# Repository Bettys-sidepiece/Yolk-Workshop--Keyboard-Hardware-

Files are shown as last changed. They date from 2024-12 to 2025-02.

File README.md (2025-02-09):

## License

The Yolk Keyboard hardware is licensed under the **TAPR Open Hardware License (TAPR OHL).**  
License: TAPR OHL  
[Read the full license](https://www.tapr.org/ohl.html)  

### **About the Yolk Keyboard Hardware**
The Yolk Keyboard consists of four PCBs:
- **Slaptic System**: Slide + haptic feedback module
- **Germinal Disc**: Keyboard (human input device)
- **Vitillus**: Main controller PCB
- **Proximity Sensor**: Detects user presence

### **Core Components**
- **Microcontroller**: STM32L702
- **Bluetooth Module**: Microchip BM71 for BLE connectivity
- **Lighting**: RGB LEDs
- **Additional Features**: Haptic feedback, capacitive touch sensing, and advanced power management

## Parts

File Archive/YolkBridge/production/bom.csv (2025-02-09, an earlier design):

Designator | Footprint | Quantity | Value | LCSC Part #
C1, C2, C3, C5 | 0603 | 4 | 100n
C4 | 0603 | 1 | 470n
C6, C7 | 0603 | 2 | 1u
D1 | D_SOD-323_HandSoldering | 1 | BAT60BE6359HTMA1
D2 | 0603 | 1 | TXLED
D3 | 0603 | 1 | RXLED
D4 | SOT-23-6 | 1 | ESDA6V1BC6
FB1 | 0603 | 1 | 100R @ 100MHz
J1 | USB_A_Molex_48037-2200_Horizontal | 1 | USB_A
J2 | 5037630491 | 1 | UART
R1, R2 | 0603 | 2 | 27R
R3, R4 | 0603 | 2 | 10k
R5, R6 | 0603 | 2 | 330R
U1 | SOT-23-6 | 1 | USBLC6-2SC6
U2 | SOT-23-5 | 1 | MIC5504-3.3YM5
U3 | QFN-16-1EP_4x4mm_P0.65mm_EP2.1x2.1mm | 1 | FT230XQ

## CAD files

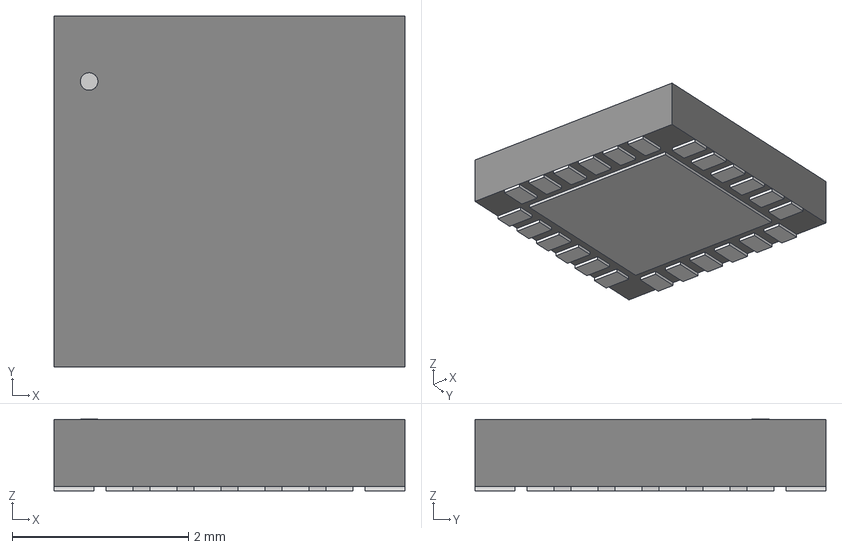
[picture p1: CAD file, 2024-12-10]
Yolk Workshop - Germinal Disc/KiCad Components/3D/PWQN0024KG-A_REN.step
3.99 x 3.99 x 0.815 mm

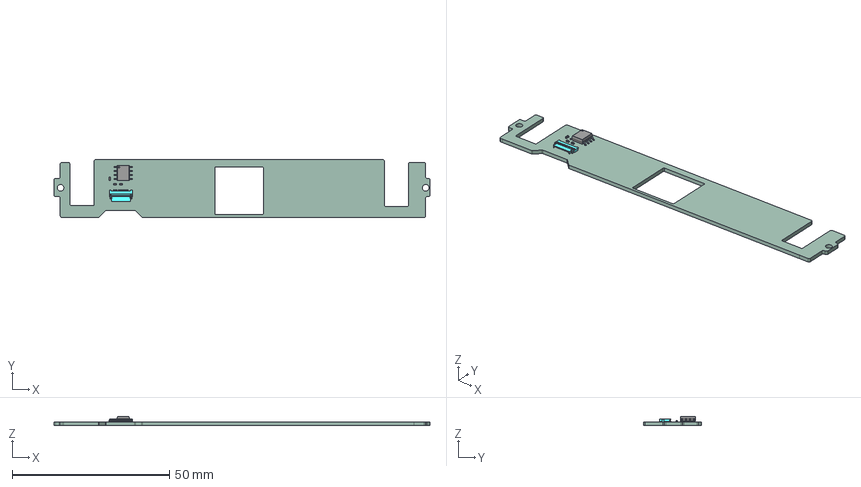
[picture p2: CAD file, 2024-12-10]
Yolk Workshop - ProxSense/capacitive_proxsensor.step
119.6 x 18.4 x 3.00 mm
ASSEMBLY
R_0402_1005Metric x 2
C_0402_1005Metric
pico_stroke_capacitive_sensor_PCB

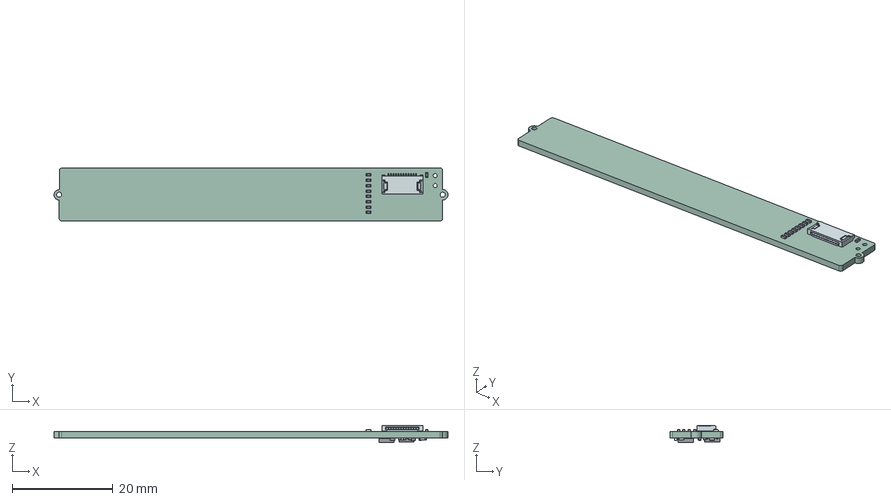
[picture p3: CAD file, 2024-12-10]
Yolk Workshop - Slaptic Engine/slaptic_engine_1.step
78.1 x 10.5 x 3.40 mm
512811298wbm000_01
R_0402_1005Metric x 16
ASSEMBLY
C_0402_1005Metric x 5
DRB0008A_ASM
pico_stroke_slider_PCB

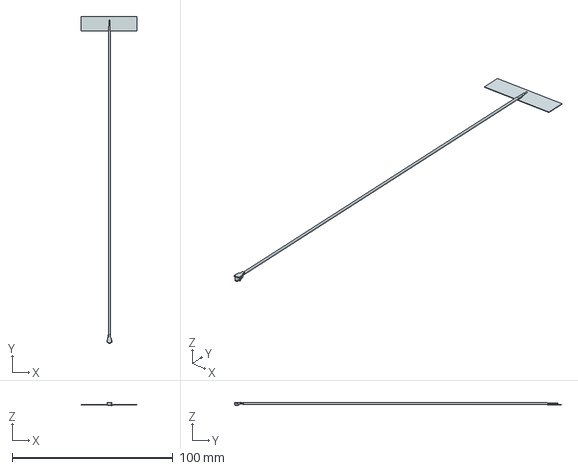
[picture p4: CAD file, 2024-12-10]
Yolk Workshop - Germinal Disc/Components/1461539200.stp
34.9 x 203.6 x 2.15 mm

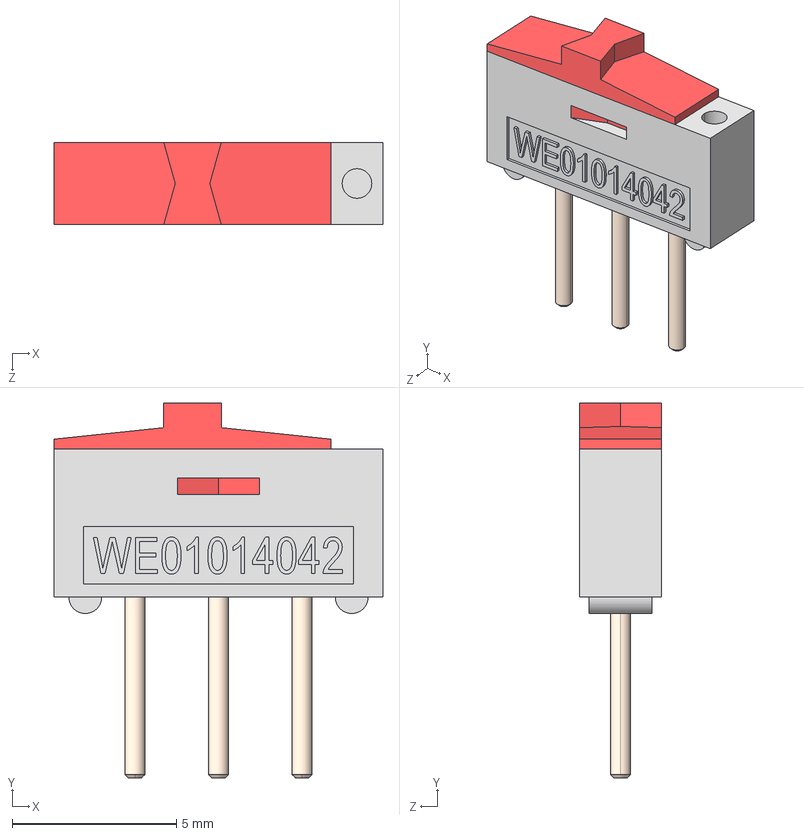
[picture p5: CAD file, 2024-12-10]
Yolk Workshop - Germinal Disc/KiCad Components/3D/450301014042.stp
10.0 x 11.4 x 2.50 mm

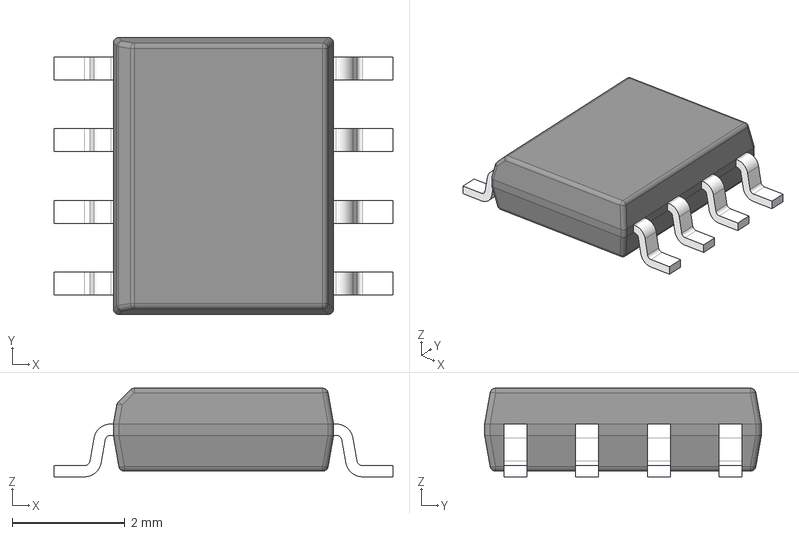
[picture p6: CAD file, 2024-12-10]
Yolk Workshop - Germinal Disc/KiCad Components/3D/UCC27212AQDDARQ1.stp
6.00 x 4.90 x 1.57 mm
BODY-SO
LEAD-SO x 8
THERMALPAD-SO

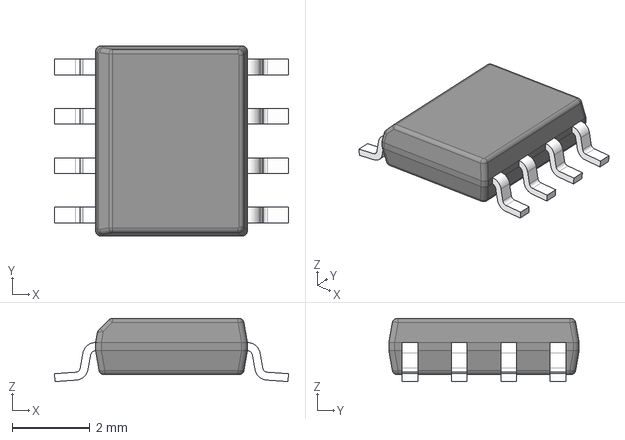
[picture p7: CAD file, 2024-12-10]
Yolk Workshop - Germinal Disc/KiCad Components/3D/UCC27284QDRQ1.stp
6.02 x 4.90 x 1.63 mm
BODY-SO
LEAD-D0008A x 8

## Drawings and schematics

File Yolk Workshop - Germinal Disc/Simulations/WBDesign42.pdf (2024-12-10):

## WEBENCH ® Design Report

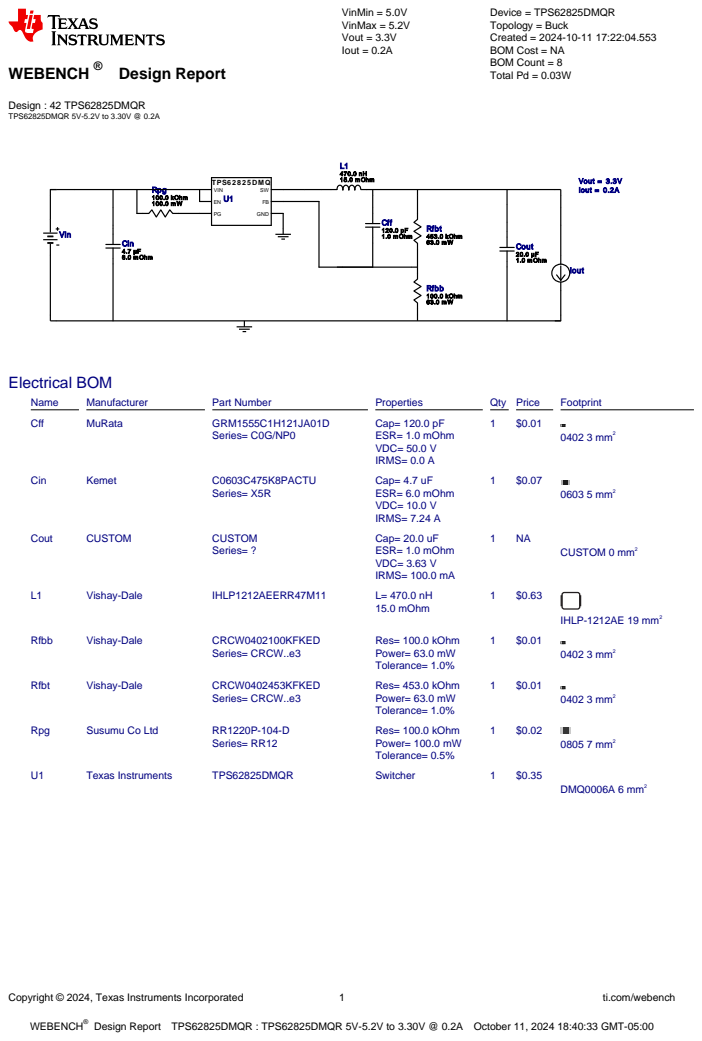
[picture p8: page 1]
Copyright © 2024, Texas Instruments Incorporated; ti.com/webench; WEBENCH®; Design : 42 TPS62825DMQR TPS62825DMQR 5V-5.2V to 3.30V @ 0.2A; VinMin = 5.0V VinMax = 5.2V Vout = 3.3V Iout = 0.2A; Cin 4.7 µF 6.0 m Ohm; Rfbb 100.0 kOhm 63.0 m W; Rfbt 453.0 kOhm 63.0 m W; Vout = 3.3V Iout = 0.2A; TPS6 2 8 2 5 DM Q; GND; VIN; Cout 20.0 µF 1.0 m Ohm; L1 470.0 nH 15.0 m Ohm; Rpg 100.0 kOhm 100.0 m W; Cff; 120.0 pF Vin; 1.0 m Ohm; Iout; Electrical BOM; Name; Manufacturer; Part Number; Properties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

Device = TPS62825DMQR
Topology = Buck
Created = 2024-10-11 17:22:04.553
BOM Cost = NA
BOM Count = 8
Total Pd = 0.03W

Design Report TPS62825DMQR : TPS62825DMQR 5V-5.2V to 3.30V @ 0.2A October 11, 2024 18:40:33 GMT-05:00

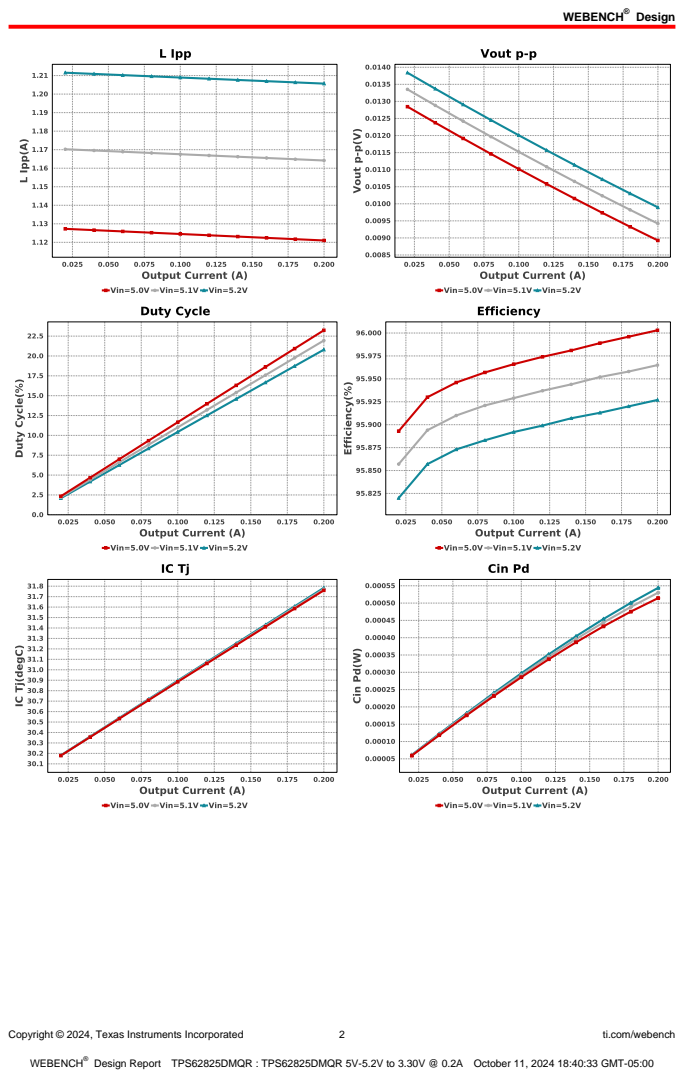
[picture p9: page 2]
Design; Copyright © 2024, Texas Instruments Incorporated; ti.com/webench

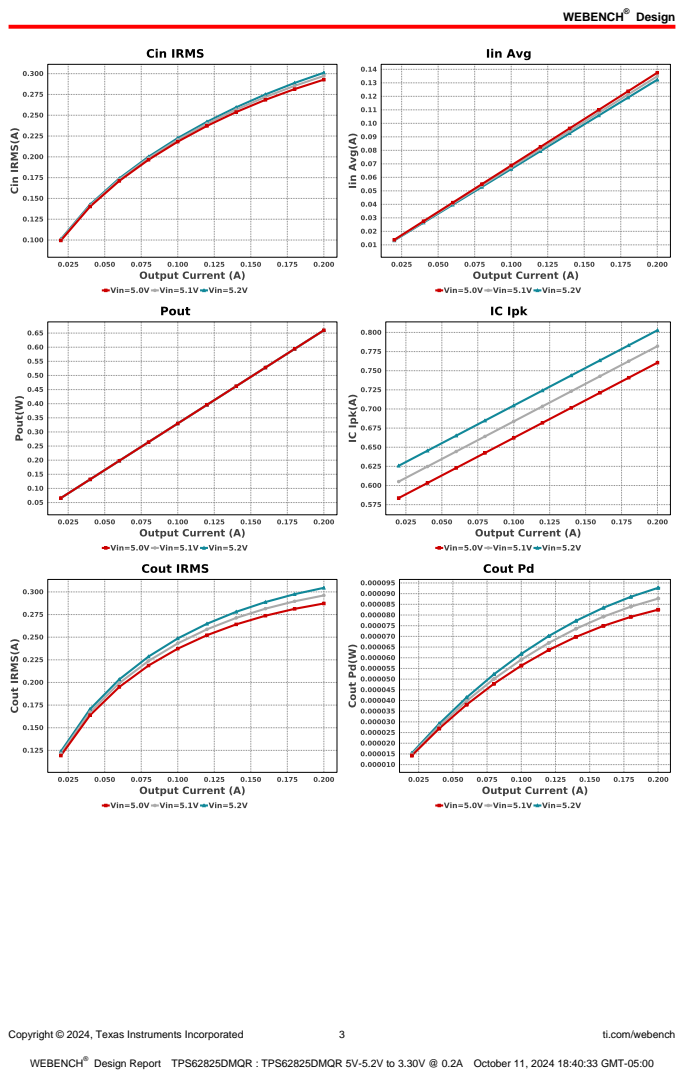
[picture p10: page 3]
Copyright © 2024, Texas Instruments Incorporated; ti.com/webench

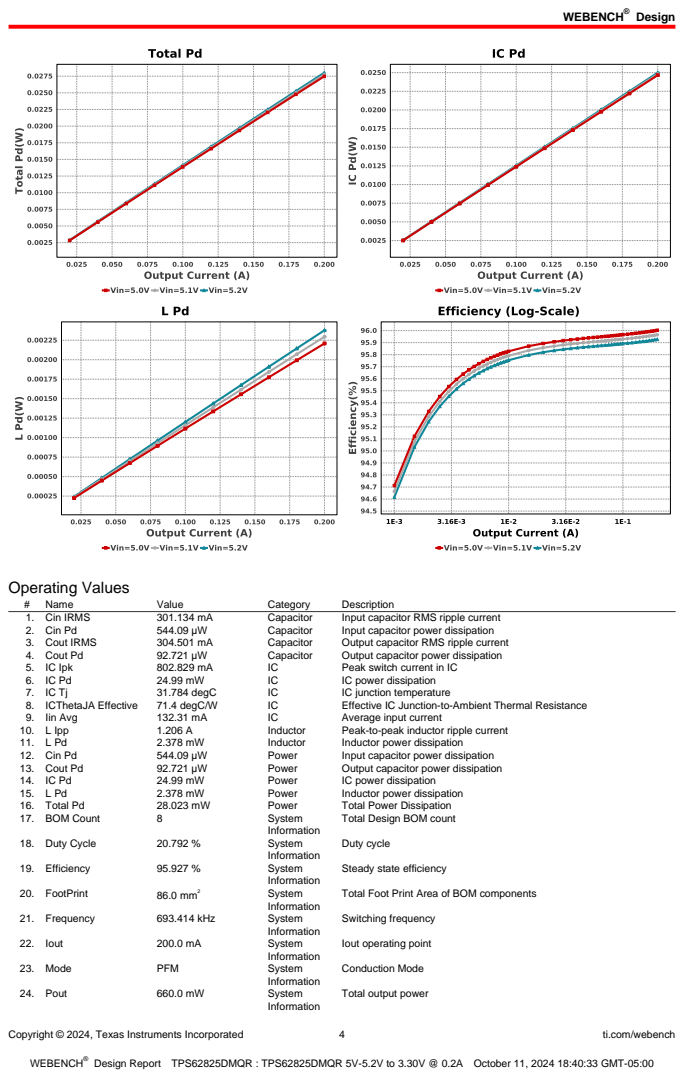
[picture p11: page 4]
Copyright © 2024, Texas Instruments Incorporated; ti.com/webench; Operating Values; Name; Value; Category; Description; 1. Cin IRMS; Capacitor; Input capacitor RMS ripple current; 2. Cin Pd; Input capacitor power dissipation; 3. Cout IRMS; Output capacitor RMS ripple current; 4. Cout Pd; Output capacitor power dissipation; 5. IC Ipk; Peak switch current in IC; IC power dissipation; 31.784 degC; IC junction temperature; 8. ICThetaJA Effective; 71.4 degC/W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

Total Design BOM count

Steady state efficiency

Total Foot Print Area of BOM components

Iout operating point

Total output power

Copyright © 2024, Texas Instruments Incorporated | 5 | ti.com/webench
# | Name | Value | Category | Description

25. Total BOM | NA | System
| | | Information | Total BOM Cost
26. Vin | 5.2 V | System
| | | Information | Vin operating point
27. Vout | 3.3 V | System
| | | Information | Operational Output Voltage
28. Vout Actual | 3.318 V | System
| | | Information | Vout Actual calculated based on selected voltage divider resistors
29. Vout Tolerance | 2.671 % | System
| | | Information | Vout Tolerance based on IC Tolerance (no load) and voltage divider resistors if applicable
30. Vout p-p | 9.896 mV | System
| | | Information | Peak-to-peak output ripple voltage

## Design Inputs

Name | Value | Description
| Iout | | 200.0 m | Maximum Output Current
VinMax | 5.2 | Maximum input voltage
VinMin | 5.0 | Minimum input voltage
Vout | 3.3 | Output Voltage
| base_pn | | TPS62825 | Base Product Number
source | DC | Input Source Type
Ta | 30.0 | Ambient temperature


Copyright © 2024, Texas Instruments Incorporated | 6 | ti.com/webench

## Assembly

## Component Testing

Some published data on components in datasheets such as Capacitor ESR and Inductor DC resistance is based on conservative values that will guarantee that the components always exceed the specification. For design purposes it is usually better to work with typical values. Since this data is not always available it is a good practice to measure the Capacitance and ESR values of Cin and Cout, and the inductance and DC resistance of L1 before assembly of the board. Any large discrepancies in values should be electrically simulated in WEBENCH to check for instabilities and thermally simulated in WebTHERM to make sure critical temperatures are not exceeded.

## Soldering Component to Board

If board assembly is done in house it is best to tack down one terminal of a component on the board then solder the other terminal. For surface mount parts with large tabs, such as the DPAK, the tab on the back of the package should be pre-tinned with solder, then tacked into place by one of the pins. To solder the tab town to the board place the iron down on the board while resting against the tab, heating both surfaces simultaneously. Apply light pressure to the top of the plastic case until the solder flows around the part and the part is flush with the PCB. If the solder is not flowing around the board you may need a higher wattage iron (generally 25W to 30W is enough).
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

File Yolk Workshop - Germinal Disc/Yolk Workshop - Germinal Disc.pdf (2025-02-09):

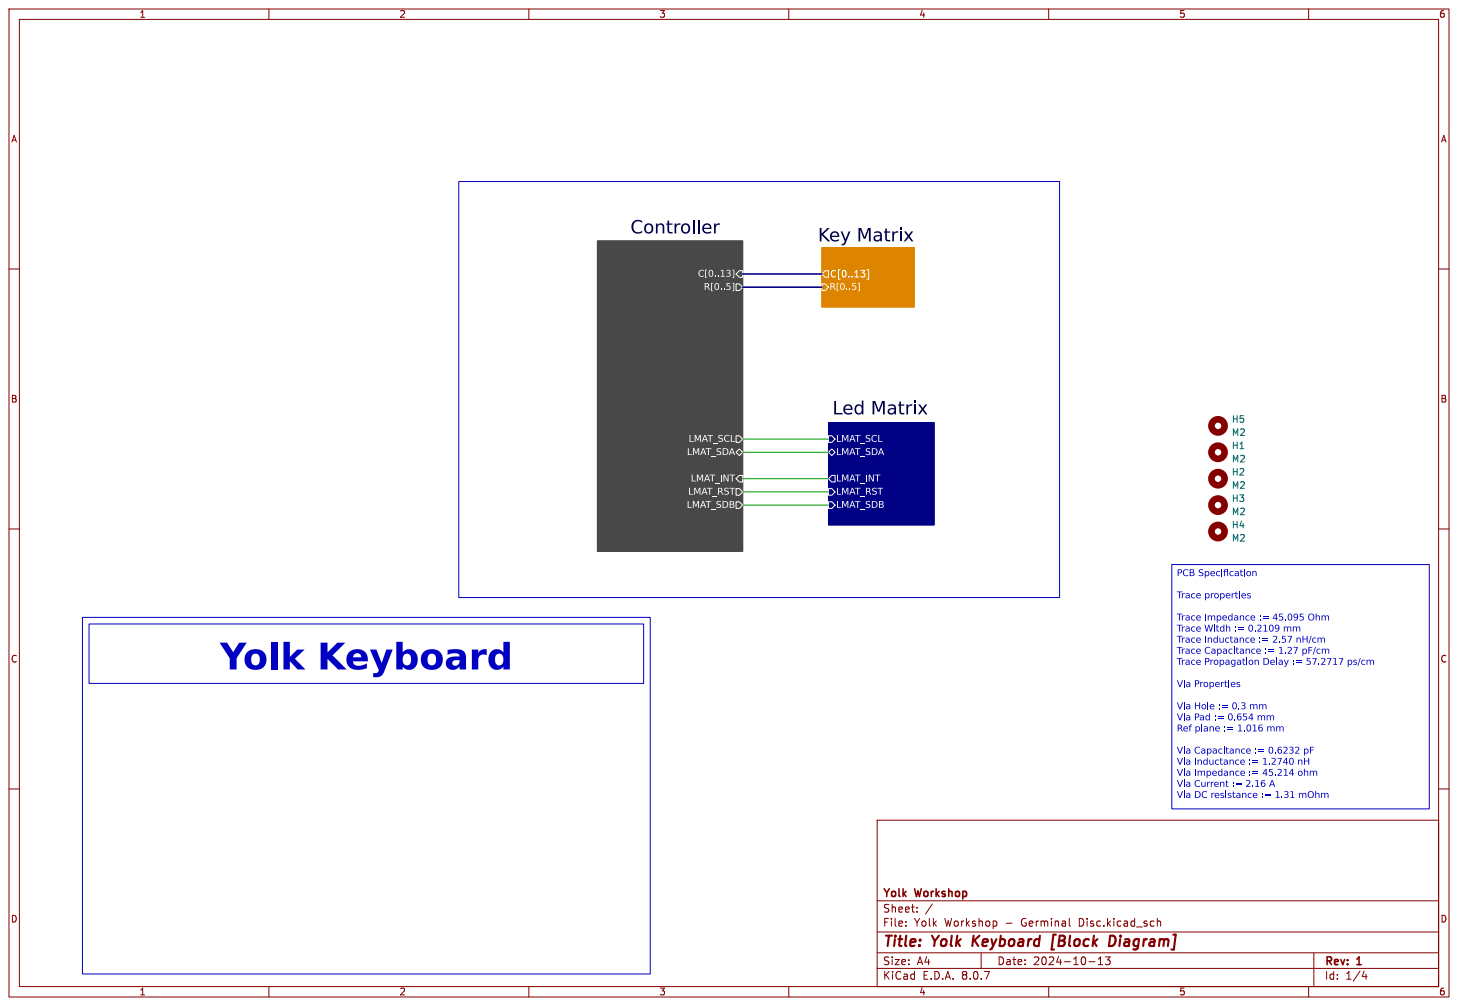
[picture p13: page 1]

H4 M2 H5 M2 H1 M2 H3 M2 H2 M2 PCB Specification Trace properties Trace Impedance := 45.095 Ohm

Trace Witdh := 0.2109 mm
Trace Inductance := 2.57 nH/cm
Trace Capacitance := 1.27 pF/cm
Trace Propagation Delay := 57.2717 ps/cm

Via DC resistance := 1.31 mOhm Yolk Keyboard

Via Properties Via Hole := 0.3 mm

Via Capacitance := 0.6232 pF Via Inductance := 1.2740 nH

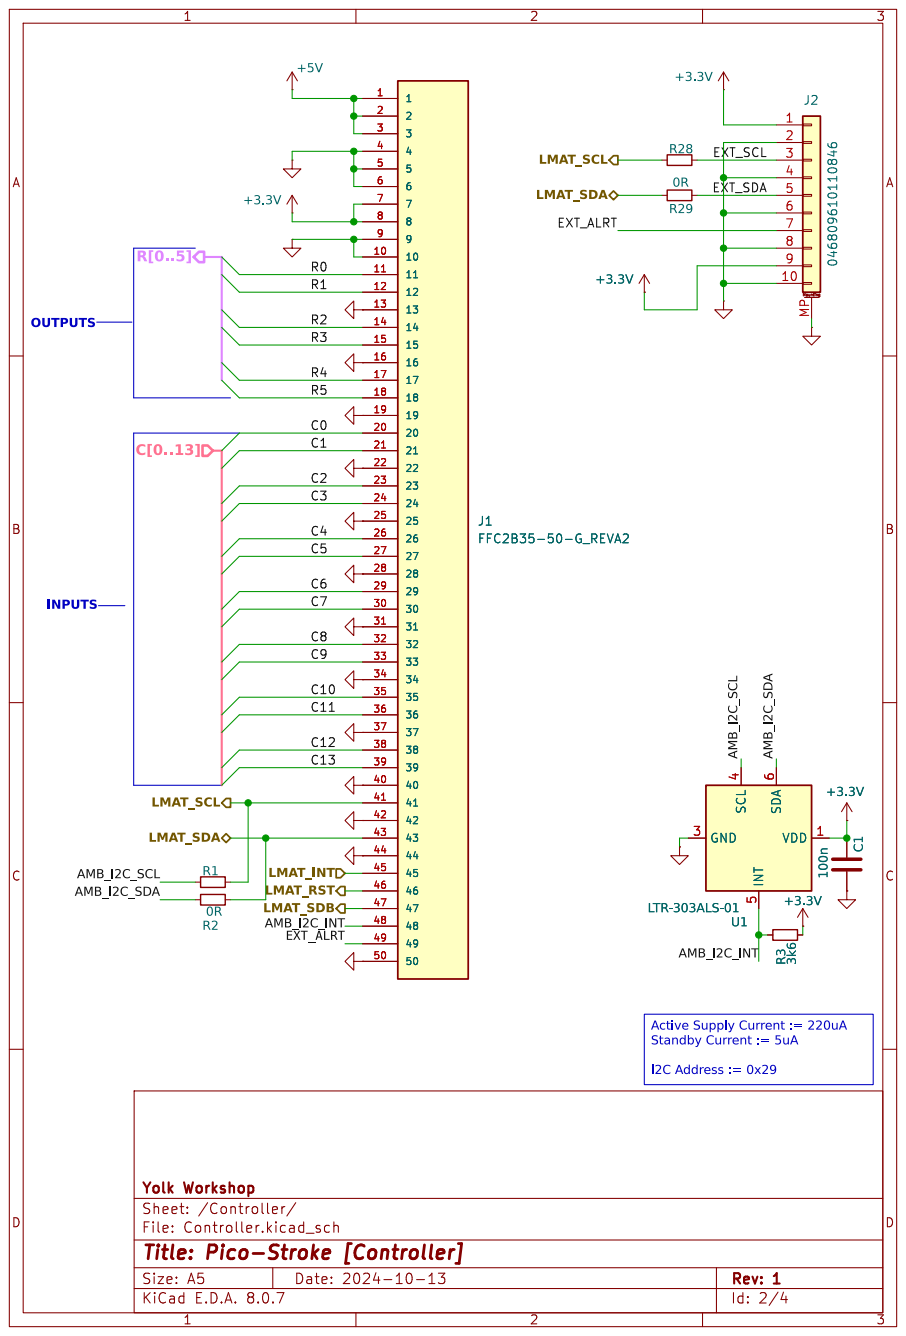
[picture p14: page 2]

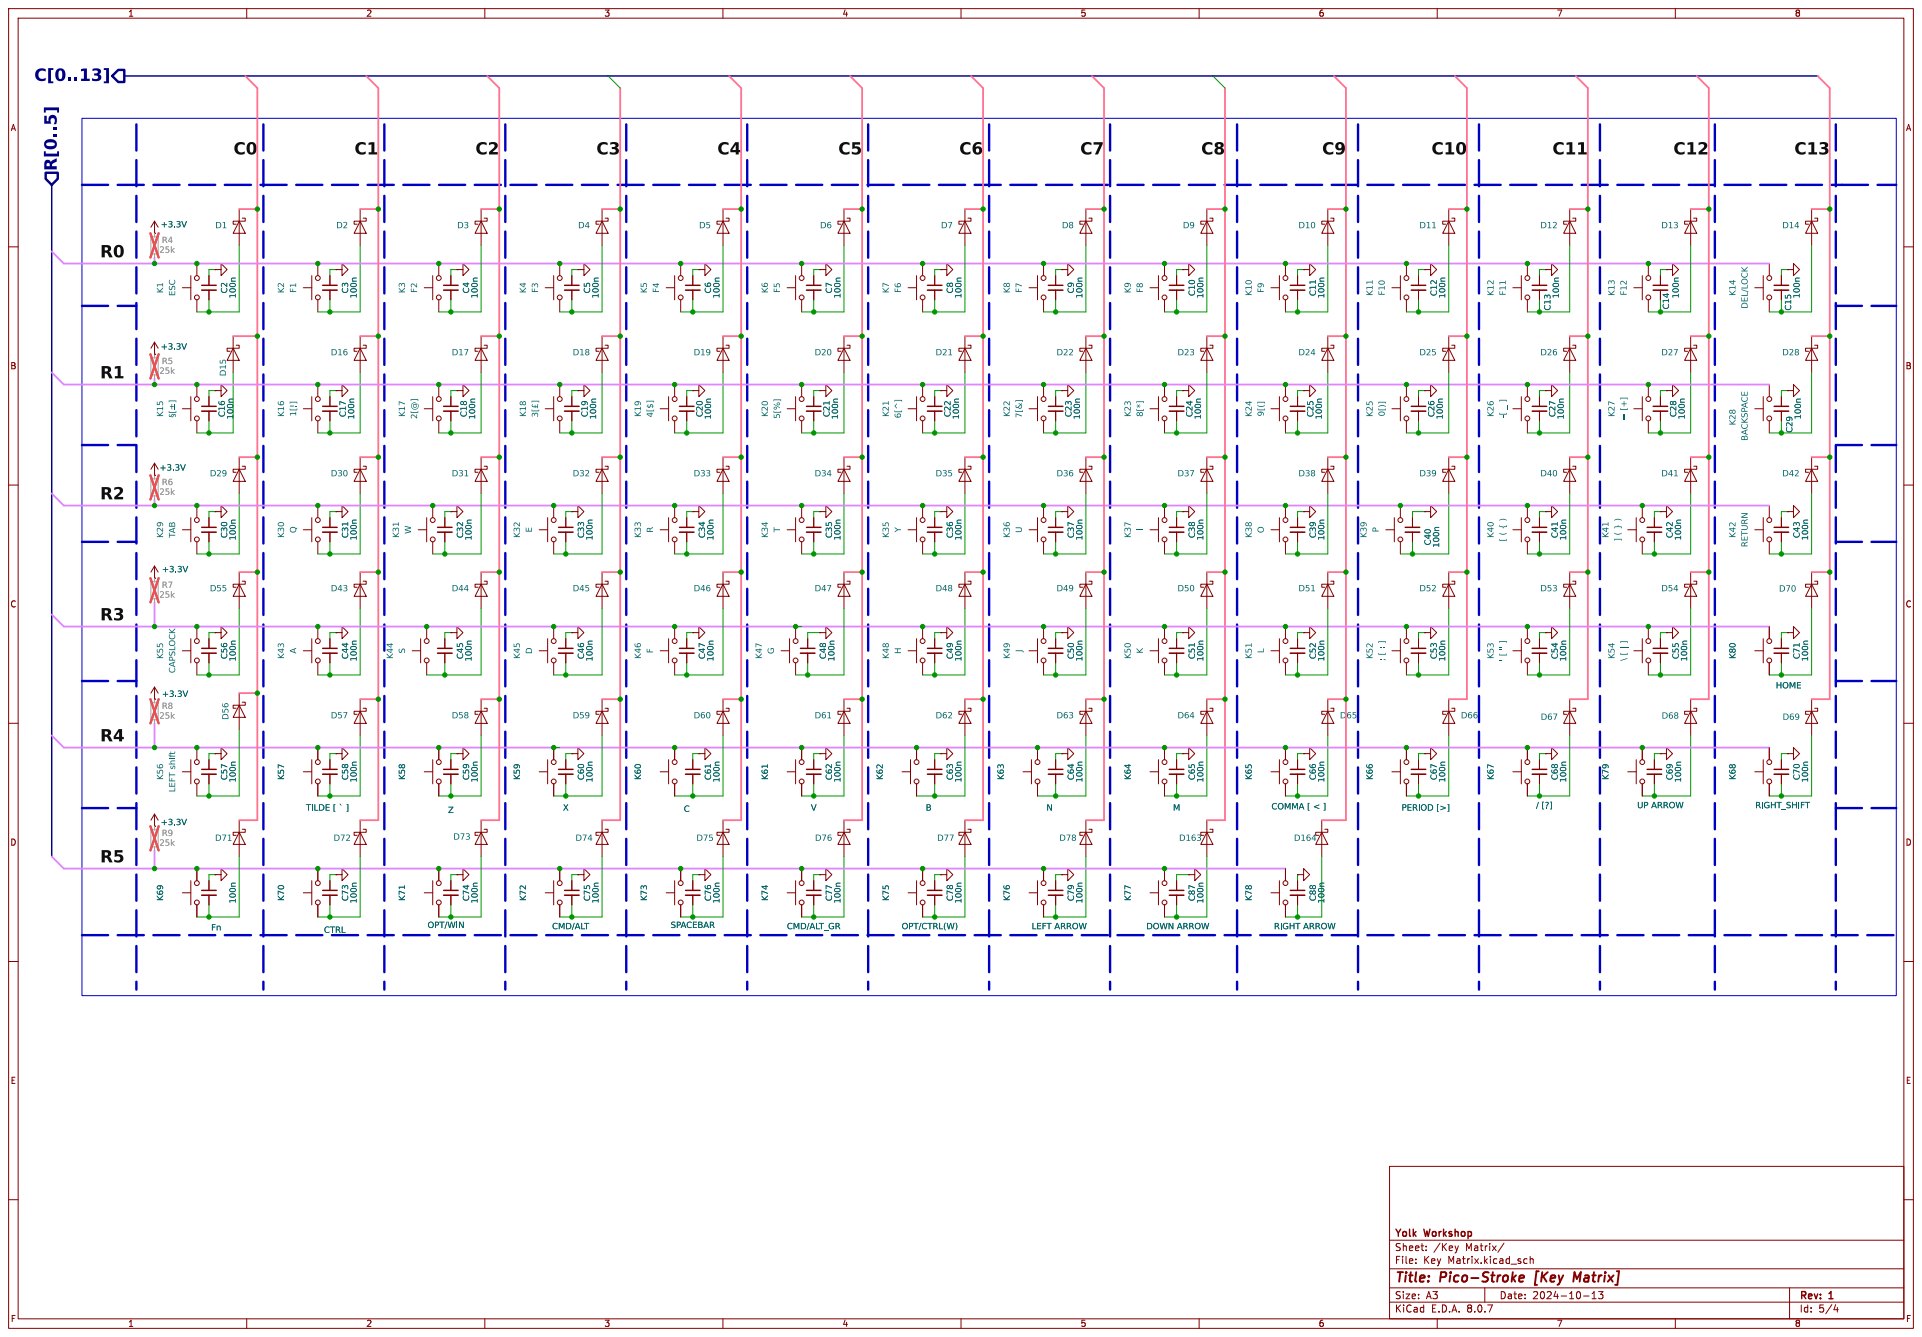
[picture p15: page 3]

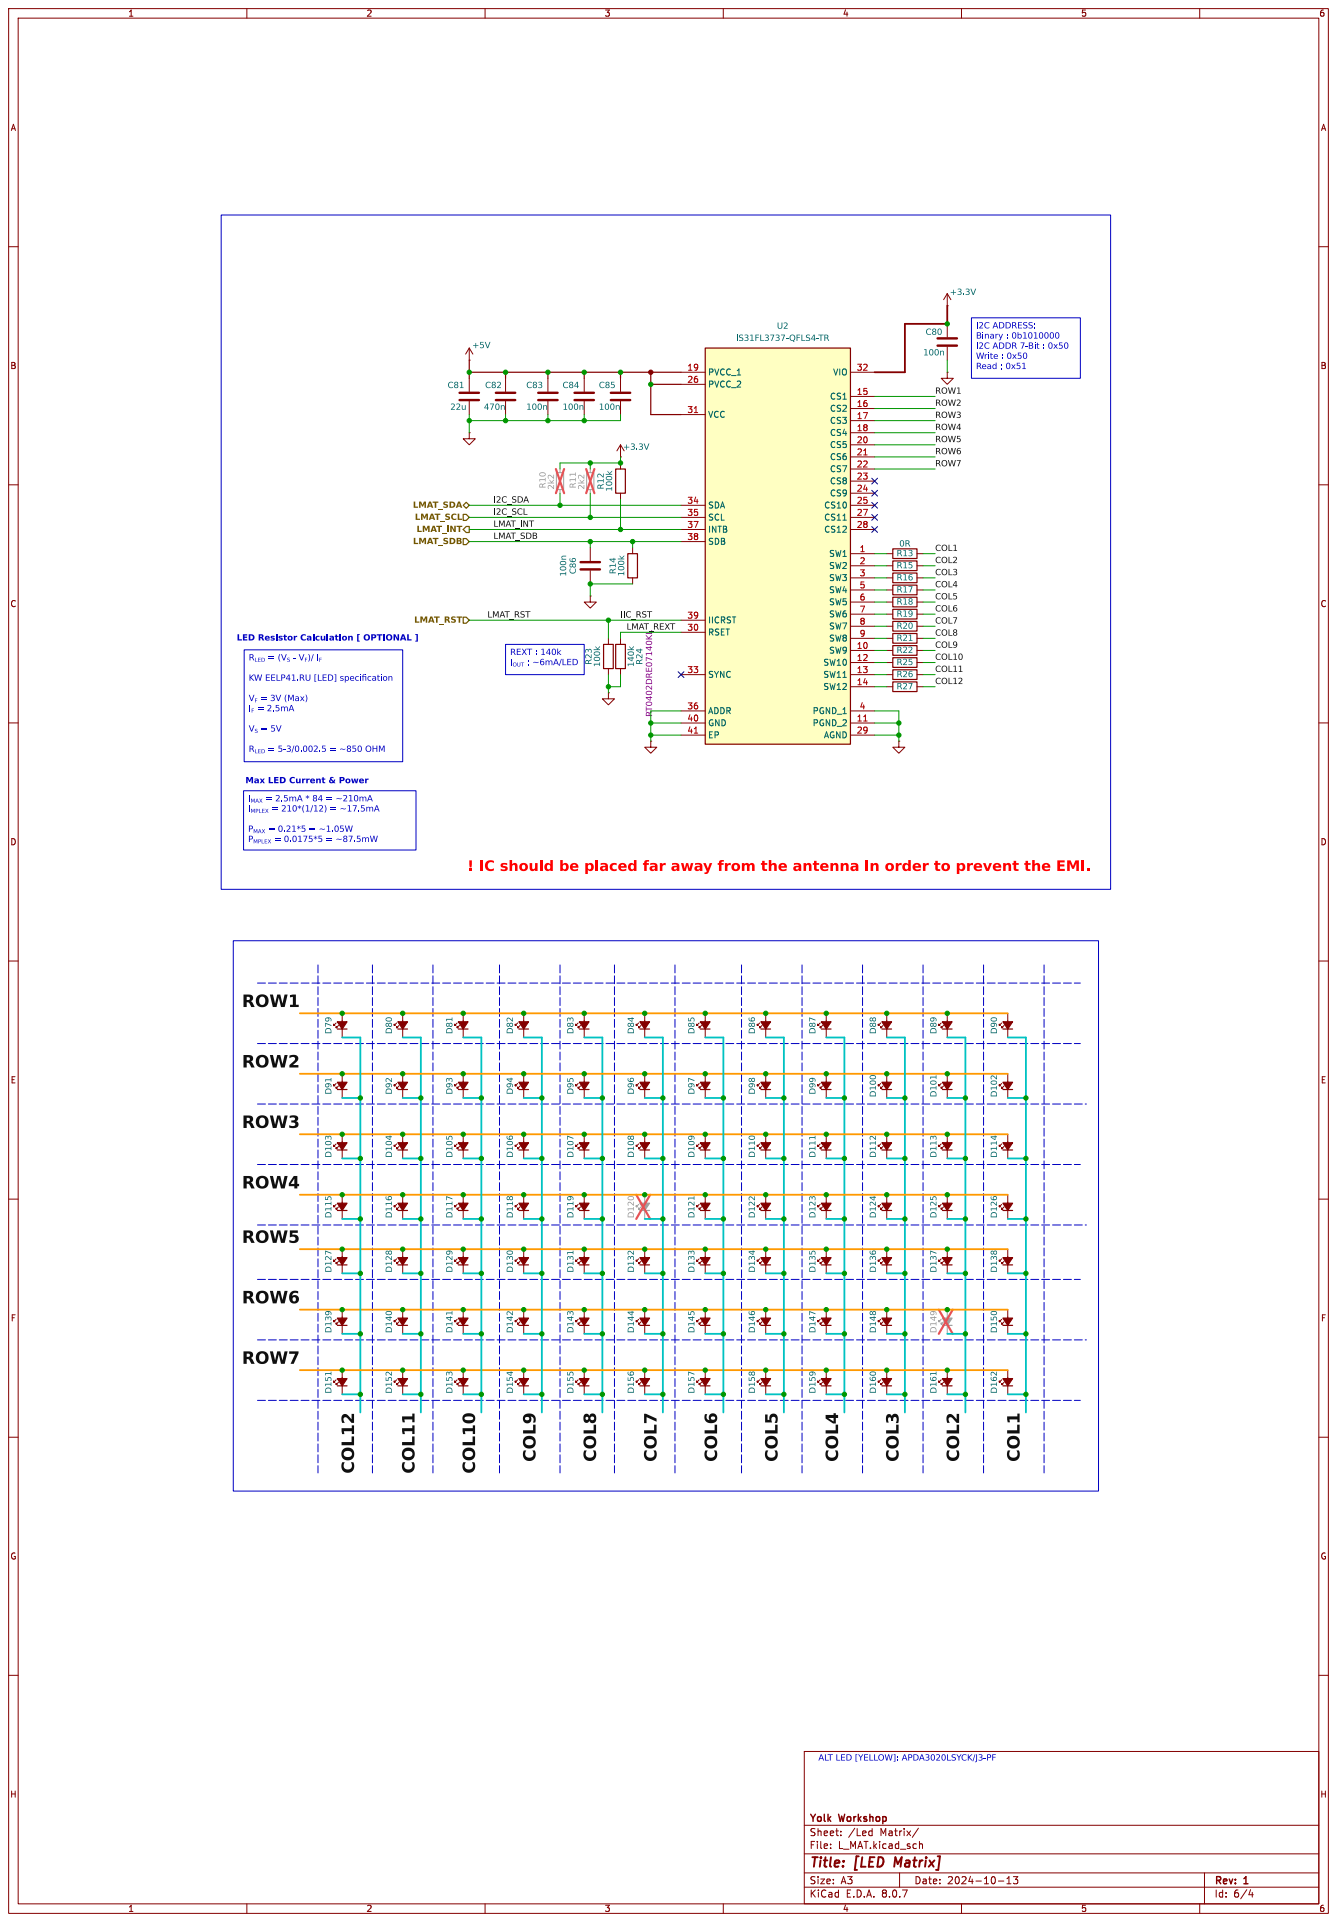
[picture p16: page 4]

I2C ADDR 7-Bit : 0x50 Write : 0x50 Read : 0x51
ROW5 ROW4 ROW1 ROW3 ROW6

R_{LED} = (V_{S} - V_{F})/ I_{F} KW EELP41.RU [LED] specification

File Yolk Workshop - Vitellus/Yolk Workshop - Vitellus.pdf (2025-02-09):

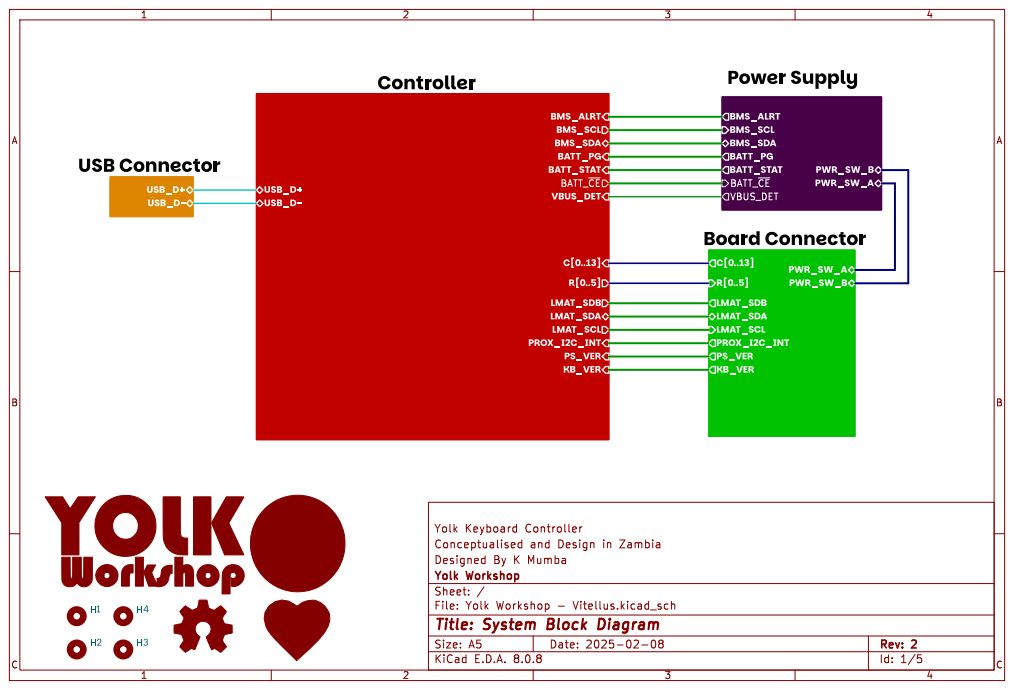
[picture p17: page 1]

Id: 1/5 Title: System Block Diagram

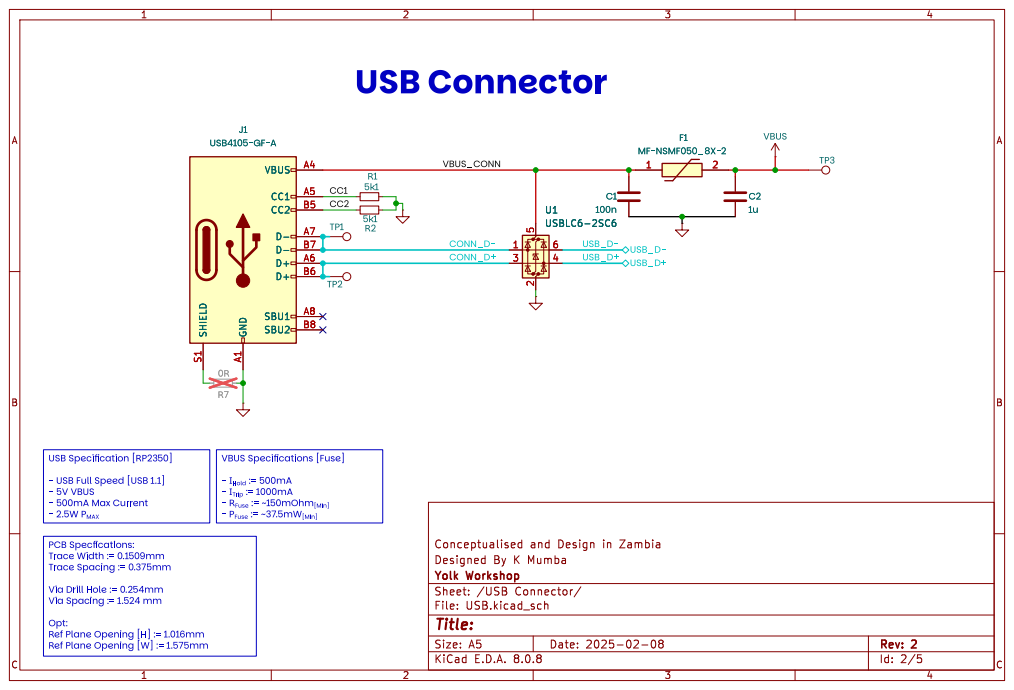
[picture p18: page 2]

USBSpecification [RP2350] - USBFull Speed [USB 1.1] - 5V VBUS

- P_{Fuse} := ~37.5mW_{[Min]} PCB Specfications: Trace Width := 0.1509mm

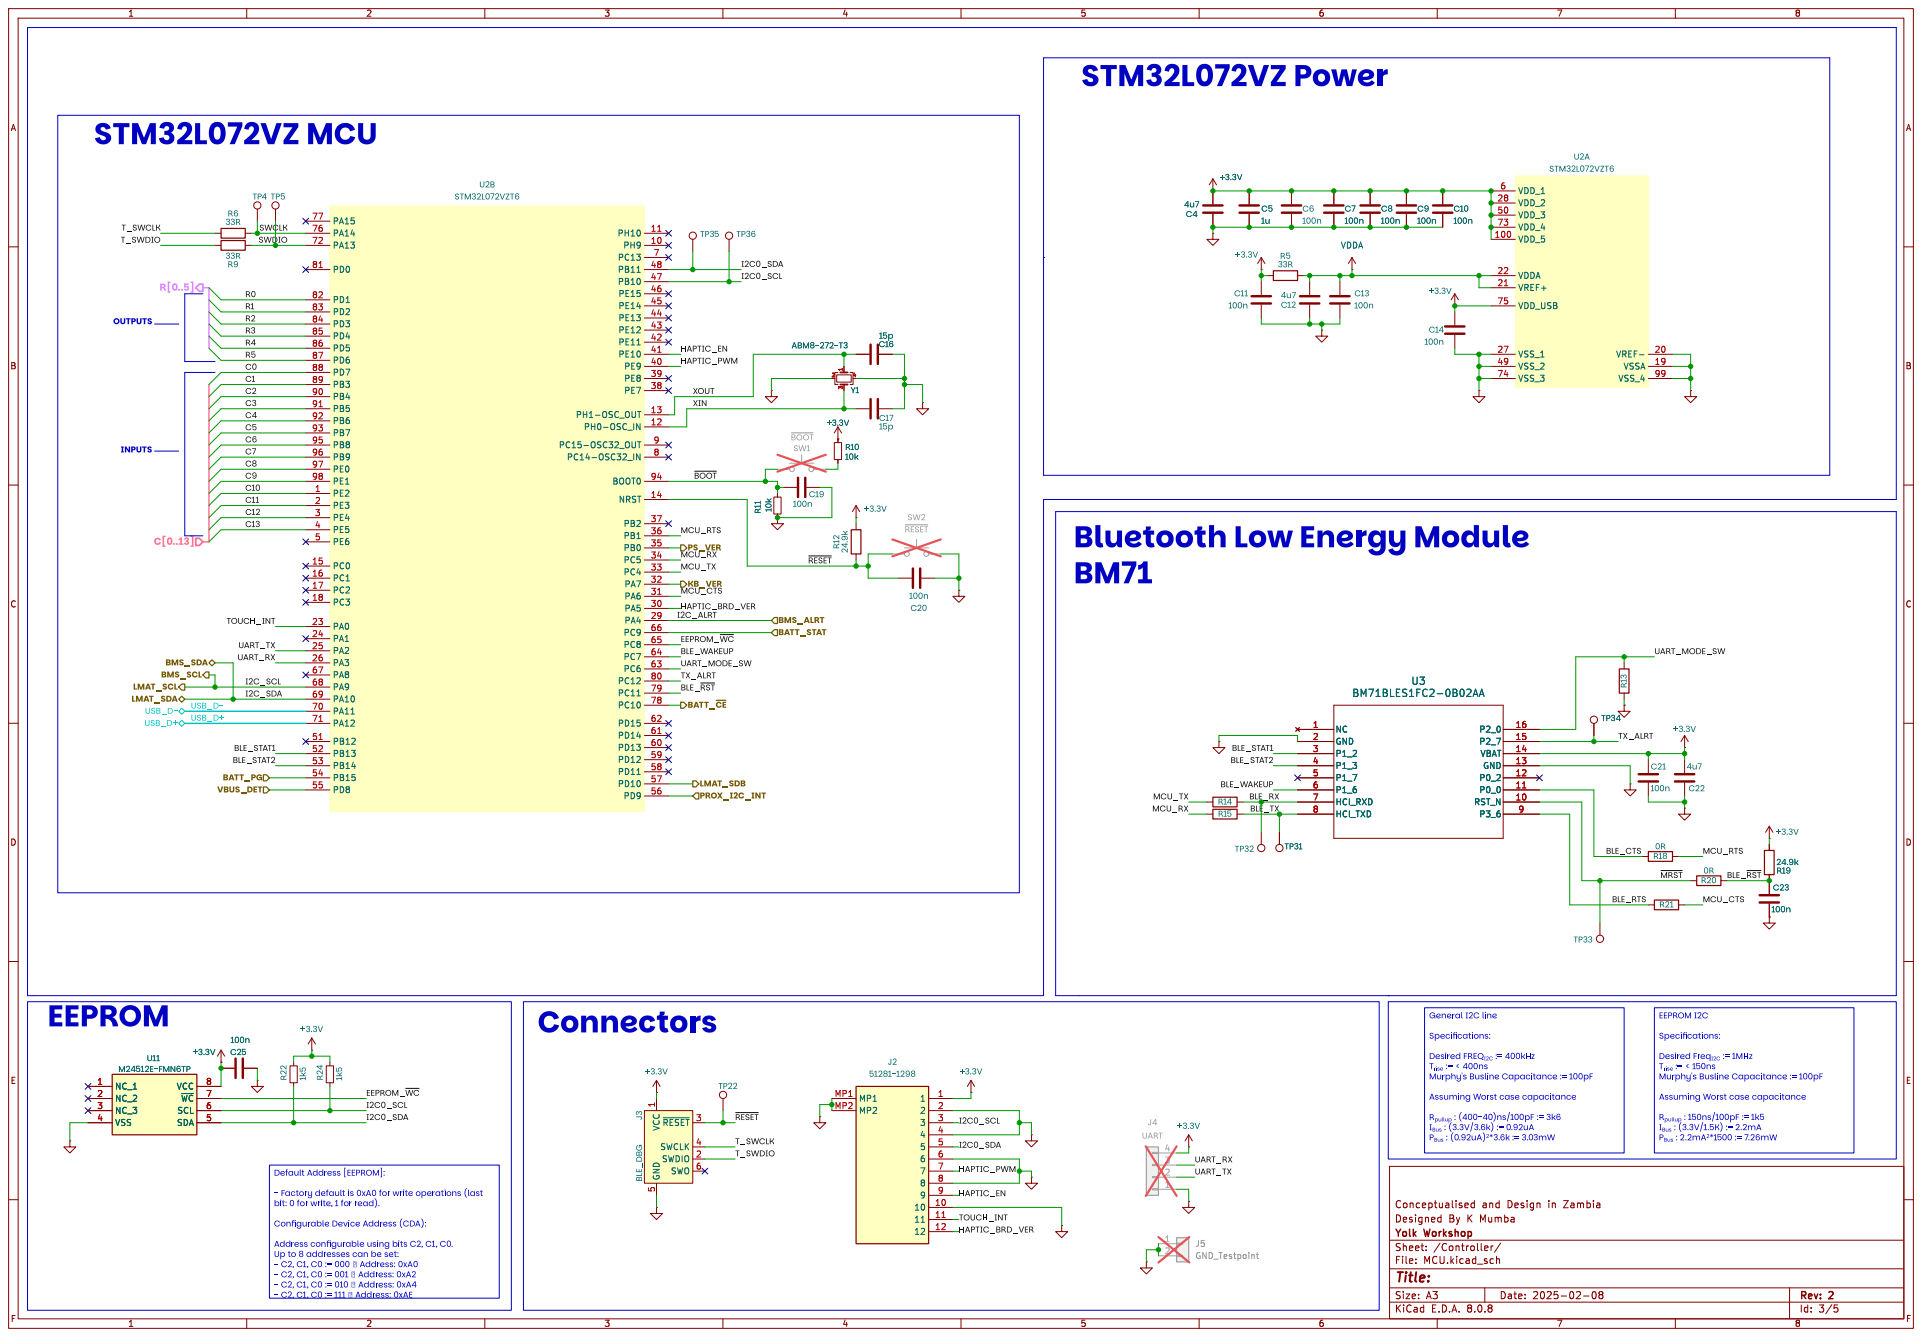
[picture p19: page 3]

General I2C line Specifications: Desired FREQ_{I2C} := 400kHz T_{rise} := < 400ns Murphy's Busline Capacitance := 100pF

Specifications: Desired Freq_{I2C} := 1MHz T_{rise} := < 150ns Murphy's Busline Capacitance := 100pF

1 SWDIO 2 ~{RESET}3 SWCLK 4 GND

Assuming Worst case capacitance

Default Address [EEPROM]: - Factory default is 0xA0 for write operations (last bit: 0 for write, 1for read).

Configurable Device Address (CDA): Address configurable using bits C2, C1, C0. Up to 8 addresses can be set: - C2, C1, C0 := 000 þÿ!’ Address: 0xA0


place R31for 5V output regulation. 1%Tol, <100 PPM,0402 +3.3VA C45

1 VOUT 2 VIN1 3 PR1 4 MODE 5 VIN2 6 ST 8 U5 TPS2116DRL TP17 PS/S 1 PGND 10

If TPS62825 is adjustable
replace R36 with 453k and
place R37 and C44 for 3.3V
output regulation. 1%Tol, <100 PPM,0402

Auxillary Power & Voltage Reference
VBATC46

Id: 4/5 Title: Power Supply and BMS


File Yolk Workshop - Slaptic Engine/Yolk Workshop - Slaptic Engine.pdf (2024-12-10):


File: pico_stroke_slider.kicad_sch Sheet: / Yolk Workshop

Id: 1/1 Title: Touch Slider & Haptic System

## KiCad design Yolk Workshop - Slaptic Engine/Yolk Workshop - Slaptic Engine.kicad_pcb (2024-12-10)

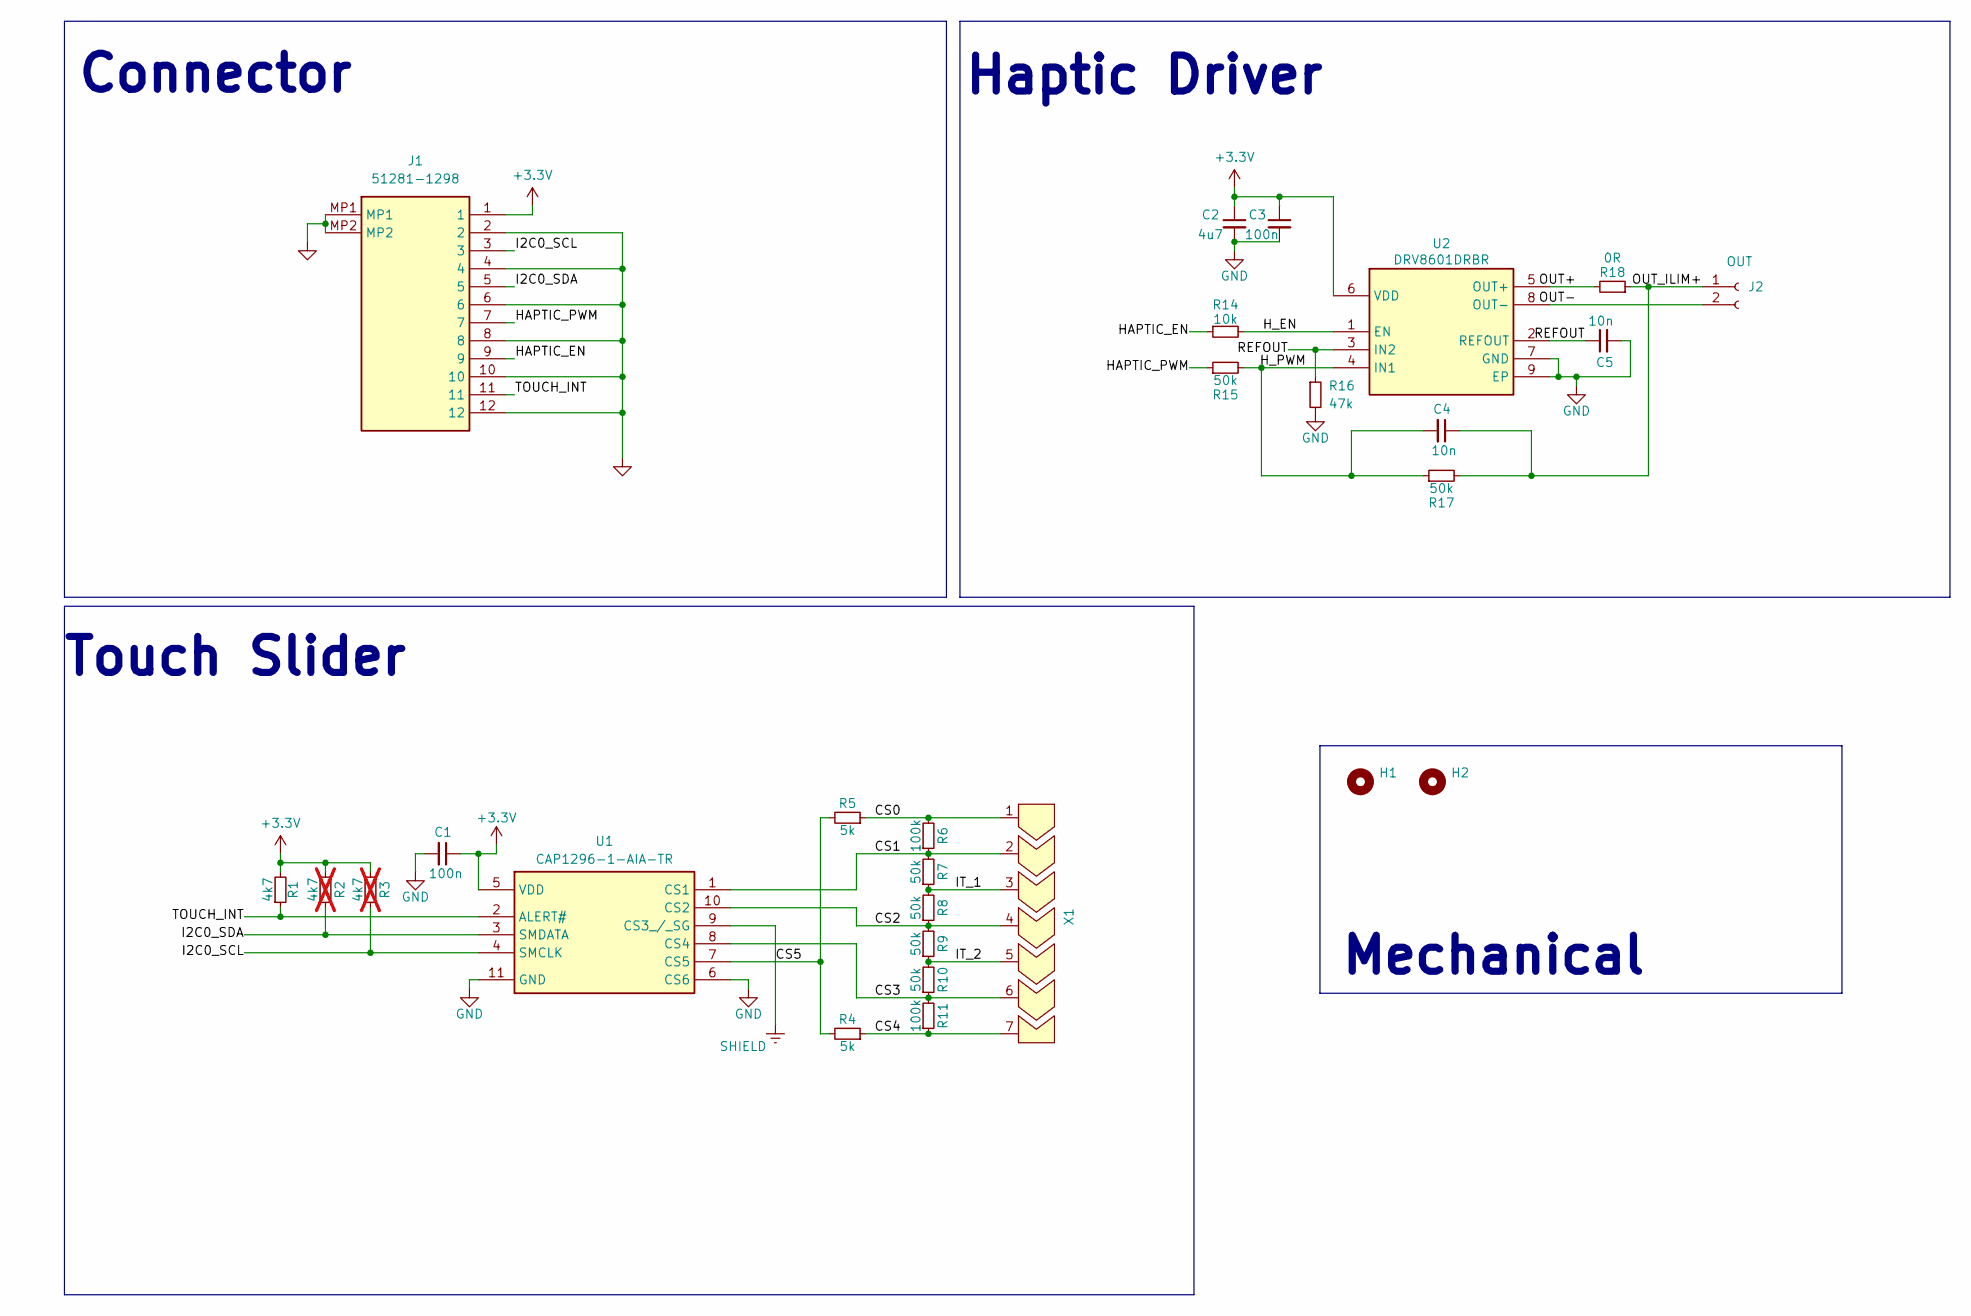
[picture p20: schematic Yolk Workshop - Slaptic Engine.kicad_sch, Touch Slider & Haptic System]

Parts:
C1, C3: 100n; C_0402_1005Metric
C2: 4u7; C_0402_1005Metric
C4, C5: 10n; C_0402_1005Metric
H1, H2: MountingHole; MountingHole_2.1mm
J1: 51281-1298; 512811298; Manufacturer_Part_Number 51281-1298; Mouser Part Number 538-51281-1298
J2: OUT; PinHeader_1x02_P2.00mm_Vertical
R1: 4k7; R_0402_1005Metric
R2, R3: 4k7; R_0402_1005Metric; not fitted
R4, R5: 5k; R_0402_1005Metric
R6, R11: 100k; R_0402_1005Metric
R7, R8, R9, R10, R15, R17: 50k; R_0402_1005Metric
R14: 10k; R_0402_1005Metric
R16: 47k; R_0402_1005Metric
R18: 0R; R_0402_1005Metric
U1: CAP1296-1-AIA-TR; SON50P300X300X90-11N-D; Manufacturer_Part_Number CAP1296-1-AIA-TR; Mouser Part Number 579-CAP1296-1-AIA-TR
U2: DRV8601DRBR; SON65P300X300X100-9N-D; Manufacturer_Part_Number DRV8601DRBR; Mouser Part Number 595-DRV8601DRBR
X1: Capacitive_slider_8x70

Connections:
+3.3V: C1.1, C2.1, C3.1, J1.1, R1.2, R2.2, R3.2, U1.5 (VDD), U2.6 (VDD)
/CS0: R5.1, R6.2, X1.1
/CS1: R6.1, R7.2, U1.1 (CS1), X1.2
/CS2: R8.1, R9.2, U1.10 (CS2), X1.4
/CS3: R10.1, R11.2, U1.8 (CS4), X1.6
/CS4: R4.1, R11.1, X1.7
/CS5: R4.2, R5.2, U1.7 (CS5)
/HAPTIC_EN: J1.9, R14.1
/HAPTIC_PWM: J1.7, R15.1
/H_EN: R14.2, U2.1 (EN)
/H_PWM: C4.2, R15.2, R17.1, U2.4 (IN1)
/I2C0_SCL: J1.3, R3.1, U1.4 (SMCLK)
/I2C0_SDA: J1.5, R2.1, U1.3 (SMDATA)
/IT_1: R7.1, R8.2, X1.3
/IT_2: R9.1, R10.2, X1.5
/OUT+: R18.2, U2.5 (OUT+)
/OUT-: J2.2, U2.8 (OUT-)
/OUT_ILIM+: C4.1, J2.1, R17.2, R18.1
/REFOUT: C5.1, R16.1, U2.2 (REFOUT), U2.3 (IN2)
/TOUCH_INT: J1.11, R1.1, U1.2 (ALERT#)
GND: C1.2, C2.2, C3.2, C5.2, J1.2, J1.4, J1.6, J1.8, J1.10, J1.12, J1.MP1, J1.MP2, R16.2, U1.6 (CS6), U1.11 (GND), U2.7 (GND), U2.9 (EP)
SHIELD: U1.9 (CS3_/_SG)

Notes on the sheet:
Connector
Mechanical
Haptic Driver
Touch Slider

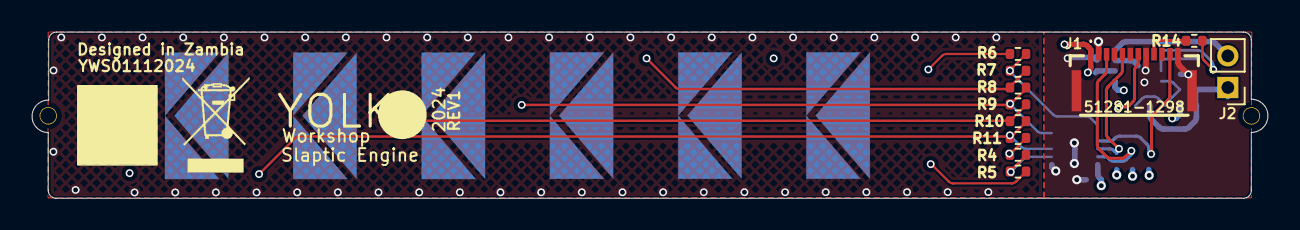
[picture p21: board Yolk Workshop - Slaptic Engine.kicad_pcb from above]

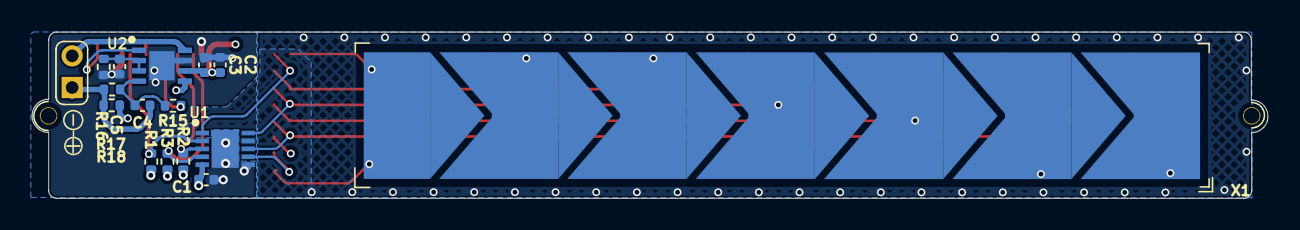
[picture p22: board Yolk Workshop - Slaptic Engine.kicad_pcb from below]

Board: 4 copper layers, 78.1 x 10.5 mm, 28 parts (15 on the bottom side), 21 nets.

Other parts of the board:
H2#2: MountingHole; MountingHole_2.1mm

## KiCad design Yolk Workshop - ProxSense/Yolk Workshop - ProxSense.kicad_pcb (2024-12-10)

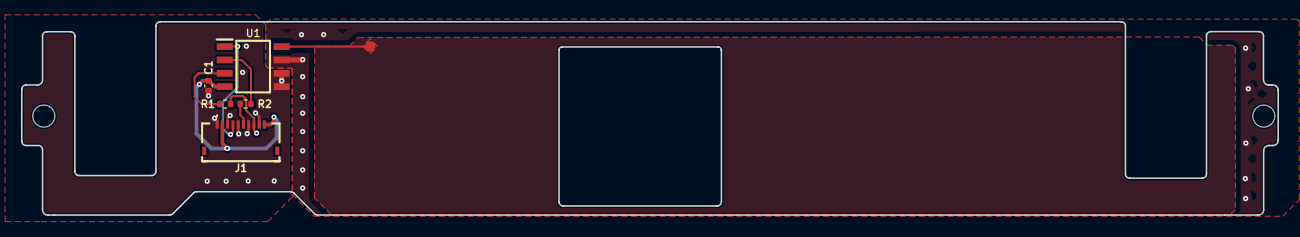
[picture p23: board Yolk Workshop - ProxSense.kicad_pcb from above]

Board: 2 copper layers, 119.6 x 18.4 mm, 5 parts (0 on the bottom side), 7 nets.

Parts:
C1: 100n; C_0402_1005Metric
J1: 046809610110846
R1, R2: 0R; R_0402_1005Metric
U1: CAP1293-1-SN; SOIC127P600X175-8N

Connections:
+3.3V: C1.1, J1.2, J1.10, U1.4 (VDD)
/EXT_ALRT: J1.4, U1.1 (ALERT#)
/EXT_SCL: J1.8, R1.2
/EXT_SDA: J1.6, R2.2
/I2C_SCL: R1.1, U1.3 (SMCLK)
/I2C_SDA: R2.1, U1.2 (SMDAT)
GND: C1.2, J1.1, J1.3, J1.5, J1.7, J1.9, U1.5 (GND), U1.6 (CS3)

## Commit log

2024-12-10 git init
    [1461539200.stp, 450301014042.stp, Controller.kicad_sch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]
2025-02-09 updates to HIP and Controller design
    [1461539200.stp, Controller.kicad_sch, FPC.kicad_sch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]

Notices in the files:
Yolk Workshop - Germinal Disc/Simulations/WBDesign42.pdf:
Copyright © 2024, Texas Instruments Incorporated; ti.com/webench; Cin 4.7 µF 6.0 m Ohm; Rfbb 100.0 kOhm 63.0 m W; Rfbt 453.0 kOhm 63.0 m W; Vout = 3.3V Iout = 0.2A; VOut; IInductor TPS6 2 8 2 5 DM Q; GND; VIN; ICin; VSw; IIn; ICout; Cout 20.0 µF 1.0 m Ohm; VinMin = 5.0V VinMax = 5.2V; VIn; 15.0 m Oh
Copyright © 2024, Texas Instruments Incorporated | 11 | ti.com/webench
